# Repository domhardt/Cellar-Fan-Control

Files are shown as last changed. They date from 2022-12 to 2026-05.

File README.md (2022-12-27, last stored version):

# Cellar-Fan-Control

## Functionality
- humidity-controlled cellar fan to dry out a cellar
- only vents the cellar if the inside dew point is higher than the putside dew point
- switches fans that are connected to WiFi plugs that run TASMOTA
- runs a website with live "view" of parameters and settings
- uses ThingSpeak for logging

## Hardware
- 1x ESP8266 WiFi microcontroller
- 2x BOSCH BME280 humidity and temperature sensor (pressure is not used)
- 2x TASMOTA-enabled WiFi socket (e.g., SONOFF S26)
- 2x fan (e.g., EBM-PAPST 4650N)

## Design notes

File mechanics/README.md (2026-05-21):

# Cellar-Fan-Control Mechanics

### BOM

- parts to obtain (for a setup with 1 fan and one filter)
    - fan
        - EBM-PAPST 4650N
        - 1 piece (buy more for a multifan setup)
    - WiFi-enabled microcontroller
        - WeMos D1 Mini
        - 1 piece
    - humidity and temperature sensors
        - BOSCH BME280
        - 2 pieces
    - TASMOTA-enabled WiFi socket
        - SONOFF S26 or SONOFF Basic
        - 1 piece (buy more for a multifan setup)
    - white UV-resistant filament for the Stevenson Screens
        - ASA or a UV-resistant PLA variant (ABS, PETG and most PLA filaments are not UV-resistant)
        - e.g. Extrudr PLA NX2 https://www.extrudr.com/en/products/catalogue/pla-nx2-wei_1964/
        - approx. 250g
    - fileament to print all the other mechanical parts
        - can be the same as the Stevenson Screens but regular PLA will do
        - approx. 250g (approx. 150g more for each additional fan mount, aprox. 85g more for each additional filter)
    
    - filter material
        - filter class G2 or better
        - 150 mm x 150 mm x 5 mm (filter can be as thick as 10 mm)
        - 1 piece (this filter should be replaced once each year or so)

- 3D printed parts
    - Fan Mount
        - own design using Fusion 360
        - printed in PLA
    - Filter Mount
        - own design using Fusion 360
        - printed in PLA
    - Stevenson Screen
        - This thing was created by Thingiverse user ORMER, and is licensed under Creative Commons - Attribution - Non-Commercial - Share Alike.
        - https://www.thingiverse.com/thing:3222598
        - printed in UV-resistant white PLA
    - WeMos D1 Mini Case
        - This thing was created by Thingiverse user NoGue, and is licensed under cc-nc-nd.
        - https://www.thingiverse.com/thing:5229342
        - printed in PLA

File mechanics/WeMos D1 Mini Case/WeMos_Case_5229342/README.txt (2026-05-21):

WeMos Case by NoGue on Thingiverse: https://www.thingiverse.com/thing:5229342

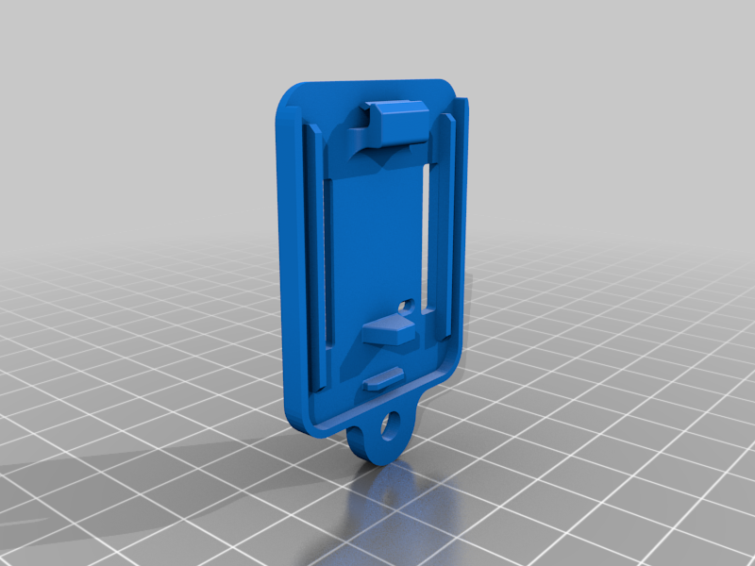
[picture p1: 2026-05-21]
mechanics/WeMos D1 Mini Case/WeMos_Case_5229342/images/02.TopCase.png

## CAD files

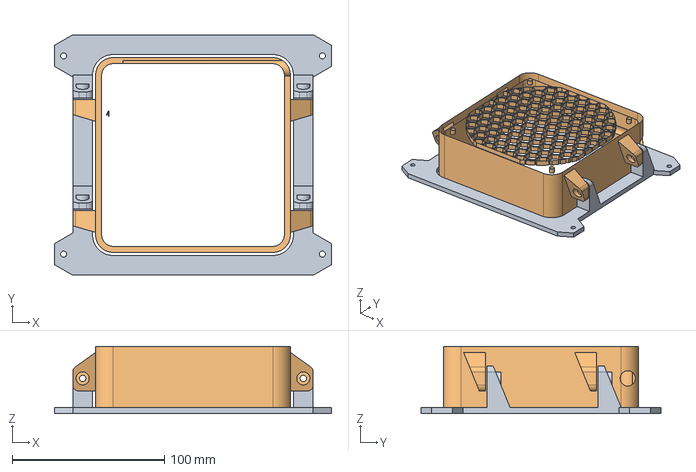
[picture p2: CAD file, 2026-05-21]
mechanics/Fan Mount/Fan Mount Silent.step
182.0 x 158.0 x 44.3 mm

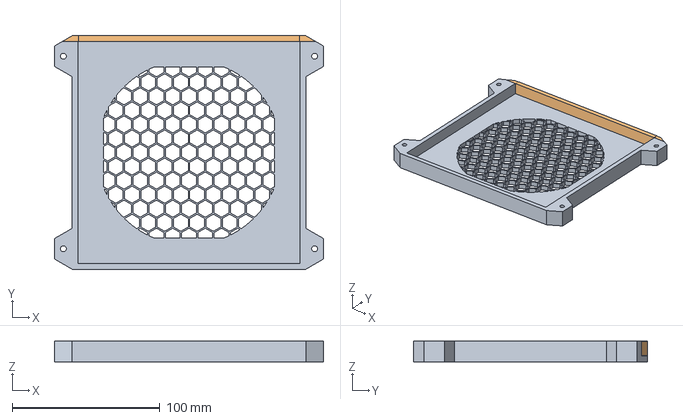
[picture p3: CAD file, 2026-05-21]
mechanics/Filter Mount/Filter Mount.step
182.0 x 158.0 x 14.0 mm

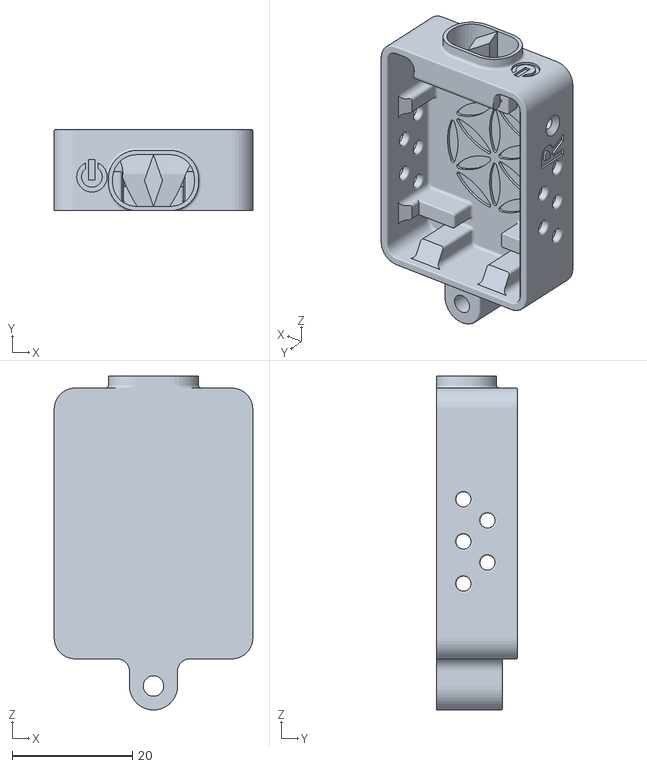
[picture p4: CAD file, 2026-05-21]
mechanics/WeMos D1 Mini Case/WeMos_Case_5229342/files/01.Base.STL
33.0 x 13.5 x 55.5

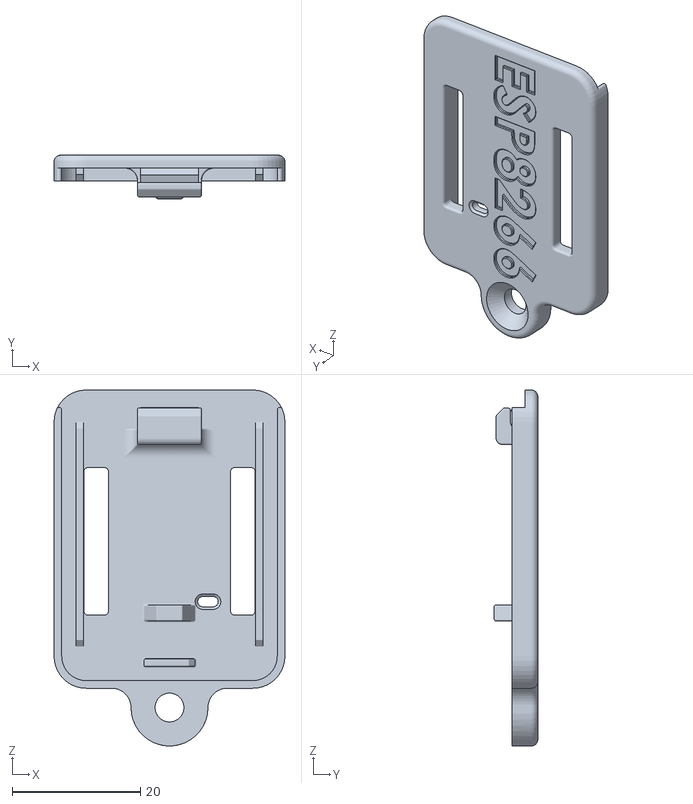
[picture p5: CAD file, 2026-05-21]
mechanics/WeMos D1 Mini Case/WeMos_Case_5229342/files/02.TopCase.STL
36.0 x 6.80 x 55.5

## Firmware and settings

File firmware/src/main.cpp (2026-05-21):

/*
 * Cellar Fan Control
 *
 * implementation for ESP8266
 * uses two DHT22 temperature and humidity sensors
 * controls two WIFI sockets running TASMOTA firmware (e.g., Sonoff S2x)
 * logs data to thingspeak
 * logic based on finite state machine (FSM)
 *
 * by Michael Domhardt
 */

// framework include
#include "Arduino.h"

// custom include
// #include "sensor/sensor_DHT22.h"
#include "sensor/sensor_BME280.h"
#include "wireless/wireless.h"
#include "finiteStateMachine/finiteStateMachine.h"
#include "logging/logging.h"
#include "webserver/webserver.h"
#include "config/config.h"

void setup()
{
  initSerial();
  initWIFI();
  initConfig();
  initSensors();
  initFans();
  initThingSpeak();
  initFiniteStateMachine();
  initWebserver();

  Serial.println(String("finished function ") + __PRETTY_FUNCTION__);
}

void loop()
{
  checkWiFi();
  server.handleClient();
  runFiniteStateMachine();
}

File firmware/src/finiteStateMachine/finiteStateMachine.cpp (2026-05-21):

// custom include
#include "finiteStateMachine.h"
#include "../config/config.h"

// for state machine
unsigned long ventilationInterval = DEFAULT_VENTILATION_INTERVAL_MINUTES * 60UL * 1000UL; // in millis
unsigned long waitInterval = DEFAULT_WAIT_INTERVAL_MINUTES * 60UL * 1000UL;        // in millis

unsigned long stateStartTimeStamp = 0;

// enum states
// {
//     NONE,
//     MEASURING,
//     VENTILATING,
//     WAITING
// };

 states state, priorState;

void initFiniteStateMachine()
{
    priorState = NONE;
    state = MEASURING;
}

void takeMeasurements()
{
    boolean measurementIntervalExpired = millis() > measurementTimestamp + measureInterval;

    if (measurementIntervalExpired)
    {
        measurementTimestamp = millis();
        readSensors();
        calcDewPoints();
        logToThingSpeak();
        printDebugInformation();
    }
}

// state methods
void measure()
{
    // initialise stuff on entering a state
    if (state != priorState)
    {
        Serial.println(String("entering state ") + __PRETTY_FUNCTION__);
        priorState = state;
    }

    // do state stuff repeatedly
    takeMeasurements();

    // check for state transition
    boolean humidityDifferenceHigh = dewPointInside - dewPointOutside > dewPointThreshold;
    boolean temperatureInsideTooLow = temperatureInside < minInsideTemperatureCutoff;
    boolean temperatureOutsideTooLow = temperatureOutside < minOutsideTemperatureCutoff;

    boolean leaveStateToVentilate = humidityDifferenceHigh && !temperatureInsideTooLow && !temperatureOutsideTooLow;

    if (leaveStateToVentilate)
    {
        state = VENTILATING;
    }

    // clean up on leaving a state
    if (state != priorState)
    {
        Serial.println(String("leaving state ") + __PRETTY_FUNCTION__);
    }
}

void ventilate()
{
    if (state != priorState)
    { // initialise stuff on entering a state
        Serial.println(String("entering state ") + __PRETTY_FUNCTION__);
        priorState = state;
        stateStartTimeStamp = millis();
        dewPointInsideLastSwicthingTime = dewPointInside;
        fansOn();
    }

    // do state stuff repeatedly
    takeMeasurements();

    // check for state transition
    boolean ventilationIntervalExpired = millis() > stateStartTimeStamp + ventilationInterval;
    boolean temperatureInsideTooLow = temperatureInside < minInsideTemperatureCutoff;
    boolean temperatureOutsideTooLow = temperatureOutside < minOutsideTemperatureCutoff;
    boolean humidityOutsideTooHigh = dewPointOutside > dewPointInsideLastSwicthingTime - (dewPointThreshold / 2);

    boolean leaveStateToWaiting = ventilationIntervalExpired || temperatureInsideTooLow || temperatureOutsideTooLow || humidityOutsideTooHigh;

    if (leaveStateToWaiting)
    {
        Serial.println(String("ventilationIntervalExpired=") + ventilationIntervalExpired);
        Serial.println(String("temperatureInsideTooLow=") + temperatureInsideTooLow);
        Serial.println(String("humidityOutsideTooHigh=") + humidityOutsideTooHigh);
        state = WAITING;
    }

    // clean up on leaving a state
    if (state != priorState)
    {
        fansOff();
        Serial.println(String("leaving state ") + __PRETTY_FUNCTION__);
    }
}

void wait()
{
    if (state != priorState)
    { // initialise stuff on entering a state
        Serial.println(String("entering state ") + __PRETTY_FUNCTION__);
        priorState = state;
        stateStartTimeStamp = millis();
    }

    // do state stuff repeatedly
    takeMeasurements();

    // check for state transition
    boolean waitIntervalExpired = millis() > stateStartTimeStamp + waitInterval;

    boolean leaveStateToMeasuring = waitIntervalExpired;

    if (leaveStateToMeasuring)
    {
        state = MEASURING;
    }

    // clean up on leaving a state
    if (state != priorState)
    {
        Serial.println(String("leaving state ") + __PRETTY_FUNCTION__);
    }
}

void runFiniteStateMachine()
{
    switch (state)
    {
    case NONE:
        state = MEASURING;
        break;
    case MEASURING:
        measure();
        break;
    case VENTILATING:
        ventilate();
        break;
    case WAITING:
        wait();
        break;
    }
}

String stateString()
{
    const char *stateStr[] = {"NONE", "MEASURING", "VENTILATING", "WAITING"};
    return stateStr[state];
}

String stateInfo () {
    String result = "State: " + stateString();
    return result;
}

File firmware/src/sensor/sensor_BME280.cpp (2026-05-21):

// custom include
#include "sensor_BME280.h"
#include "../config/config.h"

// library include
#include <Wire.h>
#include <Adafruit_Sensor.h>
#include "Adafruit_BME280.h"

Adafruit_BME280 bmeInside, bmeOutside;

unsigned long measureInterval = DEFAULT_MEASURE_INTERVAL_MINUTES * 60UL * 1000UL; // in millis
unsigned long measurementTimestamp = 0;

int dewPointThreshold = DEFAULT_DEW_POINT_THRESHOLD;
int minInsideTemperatureCutoff = DEFAULT_MIN_INSIDE_TEMPERATURE_CUTOFF;
int minOutsideTemperatureCutoff = DEFAULT_MIN_OUTSIDE_TEMPERATURE_CUTOFF;

float humidityInside;
float temperatureInside;
float dewPointInside;
float dewPointInsideLastSwicthingTime;

float humidityOutside;
float temperatureOutside;
float dewPointOutside;

void initSensors()
{
    // sensors on
    digitalWrite(BME280_POWER_PIN, HIGH);
    delay(25);

    // check indoor sensor status
    bool statusInside = bmeInside.begin(BME280_ADDRESS_INSIDE);

    if (!statusInside)
    {
        Serial.println("ERROR: Could not find the BME280 indoor sensor, check wiring!");
    }
    else
    {
        Serial.println("BME280 indoor sensor up and running");
    }

    // check outdoor sensor status
    bool statusOutside = bmeOutside.begin(BME280_ADDRESS_OUTSIDE);

    if (!statusOutside)
    {
        Serial.println("ERROR: Could not find the BME280 outdoor sensor, check wiring!");
    }
    else
    {
        Serial.println("BME280 outdoor sensor up and running");
    }

    digitalWrite(BME280_POWER_PIN, LOW);
}

void readSensors()
{
    // sensors on
    digitalWrite(BME280_POWER_PIN, HIGH);
    delay(25);

    // read indoor values
    humidityInside = -100.0;
    temperatureInside = -100.0;

    bool statusInside = bmeInside.begin(BME280_ADDRESS_INSIDE);

    if (statusInside)
    {
        humidityInside = bmeInside.readHumidity();
        temperatureInside = bmeInside.readTemperature();
    }
    else
    {
        Serial.println("ERROR: Could not find the BME280 indoor sensor. Check wiring!");
    }

    // read outdoor values
    humidityOutside = -100.0;
    temperatureOutside = -100.0;

    bool statusOutside = bmeOutside.begin(BME280_ADDRESS_OUTSIDE);

    if (statusOutside)
    {
        humidityOutside = bmeOutside.readHumidity();
        temperatureOutside = bmeOutside.readTemperature();
    }
    else
    {
        Serial.println("ERROR: Could not find the BME280 outdoor sensor. Check wiring!");
    }

    // sensors off
    digitalWrite(BME280_POWER_PIN, LOW);
}

float calcDewPoint(float humidity, float temperature)
{
    float k;
    k = log(humidity / 100) + (17.62 * temperature) / (243.12 + temperature);
    return 243.12 * k / (17.62 - k);
}

void calcDewPoints()
{
    dewPointInside = -100.0;
    dewPointOutside = -100.0;

    dewPointOutside = calcDewPoint(humidityOutside, temperatureOutside);
    dewPointInside = calcDewPoint(humidityInside, temperatureInside);

    Serial.println(String("finished function ") + __PRETTY_FUNCTION__);
}

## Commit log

2022-12-01 fixed SPAM on serial
    [main.cpp]
2022-12-04 refactored sensor code
2022-12-04 refactored wireless code
2026-05-21 folder structure reorganised
    [01.Base.STL, 02.TopCase.STL, Cellar Fan Control - KiCad.kicad_pcb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]
2026-05-21 Copilot centralised default values and fixed website to show them
    [finiteStateMachine.cpp, sensor_BME280.cpp, webserver.cpp]
2026-05-21 Copilot implemented WiFi watchdog incl. auto-reconnect and reboot
    [main.cpp, wireless.cpp]
2026-05-21 Copilot tried to fix unreachable config website
    [main.cpp, webserver.cpp, wireless.cpp]
